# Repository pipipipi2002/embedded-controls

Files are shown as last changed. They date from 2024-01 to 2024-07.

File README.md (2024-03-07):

# The Hardware
- [Interactive BOM](https://pipipipi2002.github.io/embedded-controls/hardware/controls-carier-board/output/interactive_bom.html)

## MCU
This sensor module will require the STM32F446VETx Module from [stm32f446vetx-dev-module](https://github.com/pipipipi2002/stm32f446vetx-dev-module)

## Sensor
No | Sensor | Description | Connection
---| --- |--- | ---
1  | ICM-40609-D | 6-axis IMU | SPI1
2  | ICM-42688-P | 6-axis IMU | SPI3
3  | BNO085      | 9-axis IMU | SPI2
4  | BMP390      | Barometer  | SPI4

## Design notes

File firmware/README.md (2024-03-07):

# Firmware
Capabilities
- Library support for 
    - 9-Axis IMU BNO08X
    - 6-Axis IMU ICM42688P
    - 6-Axis IMU ICM40609D
- Outputs data through UART (connected to the USB-C)

# Usage
```bash
$ make all      # to build 
$ make all -j8  # build with 8 worker cores
$ make stflash  # to flash
$ make clean    # to delete build outputs
```

## Dependencies
- Make and CMake
- GNU ARM toolchain
- Vscode
- OpenOCD [(install guide)](https://forum.pedalpcb.com/threads/setting-up-vscode-openocd-xpack-st-link-for-debugging-on-macos-big-sur.4861/)
- SVD file (already provided but you can get it from [here](https://github.com/cmsis-svd/cmsis-svd-data))

# VS-code 
## Setting Up
Download the necessaries extensions
- Cortex-Debug
- C/C++

Navigate to `.vscode` and edit the following files
- `c_cpp_properties.json`
    - Edit `macFrameworkPath` to your own environment
- `launch.json`
    - `configFiles`: based on the OpenOCD xpack install path
- `settings.json`
    - `cortex-debug.armToolchainPath`: to your GCC ARM toolchain path
    - `C_Cpp.default.compilerPath`: to your GCC ARM toolchain path

## Tasks
Under build group, there are 3 preconfigured tasks, same as in the Usage Section above.
Press `Ctrl+Shift+B` to bring up the vscode build panel and choose the desired action.

## Debug 
Under Debug, there are 2 preconfigured launches, as defined in `vscode/launch.json`. 
- Debug (with build)
- Attach

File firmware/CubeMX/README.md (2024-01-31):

# Details
This folder contains generated files from CubeMX (not the one inside STM32CubeIDE). The Makefile can be ignored as the overall project uses CMake which does not depend on the generated Makefile.

The startup file and linkerscript is depended by the top level CMakeLists.txt

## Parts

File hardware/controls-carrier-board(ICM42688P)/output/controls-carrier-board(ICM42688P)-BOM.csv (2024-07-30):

Comment | Designator | Footprint | LCSC
10n | C1,C2,C9,C10 | Capacitor_SMD:C_0402_1005Metric | C361206
1u | C17 | Capacitor_SMD:C_0603_1608Metric | C5673
470p | C18 | Capacitor_SMD:C_0603_1608Metric | C519409
2u2 | C19 | Capacitor_Tantalum_SMD:CP_EIA-3216-18_Kemet-A_Pad1.58x1.35mm_HandSolder | C600494
2u2 | C3,C4,C11,C12 | Capacitor_SMD:C_0402_1005Metric | C368595
0u1 | C5,C6,C7,C8,C13,C14,C15,C16 | Capacitor_SMD:C_0402_1005Metric | C432917
BAT760 | D1 | Diode_SMD:D_SOD-323 | C124187
LED | D2,D3 | LED_SMD:LED_0603_1608Metric | C131281
DF40HC_4.0_-60DS-0.4V_51_ | J1,J2 | whose_lib:DF40HC4060DS04V51 | C3647944
22 | R1,R2,R3,R4,R5,R6,R7,R8,R9,R10,R13,R14,R15,R16,R17,R18,R19,R20,R21,R22,R23,R25,R26,R27,R28,R29 | Resistor_SMD:R_0402_1005Metric | C413049
330 | R11,R12 | Resistor_SMD:R_0603_1608Metric | C441887
ICM-42688-P | U1,U2,U4,U5 | whose_lib:ICM_LGA-14_3x2.5mm_P0.5mm | C1850418
BMM150 | U3 | Package_CSP:WLCSP-12_1.56x1.56mm_P0.4mm | C171681
BMP390 | U6 | whose_lib:Bosch_LGA-10_2x2mm_P0.50mm | C9900016584
MIC5219-3.3YM5 | U7 | Package_TO_SOT_SMD:SOT-23-5 | C29613

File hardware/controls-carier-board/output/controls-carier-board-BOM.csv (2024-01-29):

Comment | Designator | Footprint | LCSC
10n | C1,C7 | Capacitor_SMD:C_0603_1608Metric | C307346
1u | C14 | Capacitor_SMD:C_0603_1608Metric | C5673
470p | C15 | Capacitor_SMD:C_0603_1608Metric | C519409
2u2 | C16 | Capacitor_Tantalum_SMD:CP_EIA-3216-18_Kemet-A_Pad1.58x1.35mm_HandSolder | C600494
2u2 | C2,C8 | Capacitor_SMD:C_0603_1608Metric | C100082
0u1 | C3,C4,C5,C6,C9,C10,C11 | Capacitor_SMD:C_0603_1608Metric | C1591
BAT760 | D1 | Diode_SMD:D_SOD-323 | C124187
LED | D2,D3 | LED_SMD:LED_0603_1608Metric | C131281
DF40HC_4.0_-60DS-0.4V_51_ | J1,J2 | whose_lib:DF40HC4060DS04V51 | C3647944
22 | R1,R2,R3,R4,R5,R6,R9,R10,R11,R12,R13,R14,R15,R16,R17,R18,R19,R20,R21,R22,R23,R24,R31,R32 | Resistor_SMD:R_0603_1608Metric | C491194
330 | R33,R34 | Resistor_SMD:R_0603_1608Metric | C441887
10k | R7,R8 | Resistor_SMD:R_0603_1608Metric | C98220
SW_DIP_x02 | SW1 | whose_lib:218-2LPSTRF | C314498
ICM-40609-D | U1 | whose_lib:ICM_LGA-24_3x3mm-P0.4mm | C5360621
BNO085X | U2 | Package_LGA:LGA-28_5.2x3.8mm_P0.5mm | C5189642
ICM-42688-P | U3 | whose_lib:ICM_LGA-14_3x2.5mm_P0.5mm | C1850418
BMP390 | U4 | whose_lib:Bosch_LGA-10_2x2mm_P0.50mm | C9900016584
MIC5219-3.3YM5 | U6 | Package_TO_SOT_SMD:SOT-23-5 | C29613

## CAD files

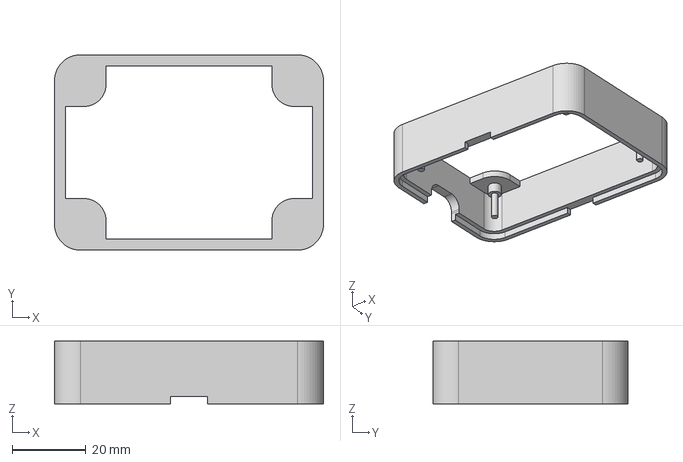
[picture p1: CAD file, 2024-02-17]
hardware/Casing-Sensor_3D-print/module-case-sensor_BODY.step
73.0 x 53.0 x 17.0 mm

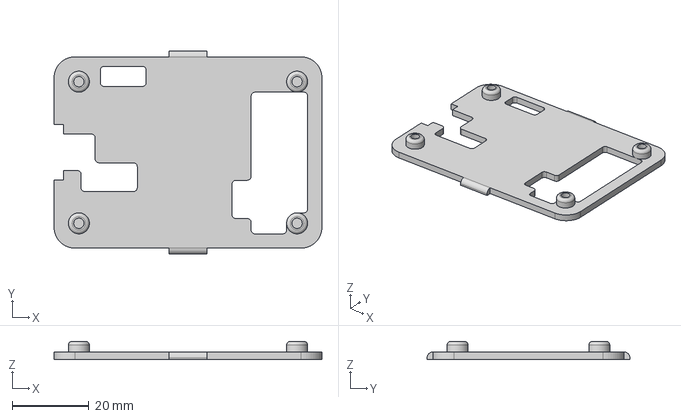
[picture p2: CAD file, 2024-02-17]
hardware/Casing-Sensor_3D-print/module-case-sensor_TOP.step
70.0 x 53.0 x 4.80 mm

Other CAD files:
hardware/Casing-Sensor_3D-print/module-case-sensor.f3z

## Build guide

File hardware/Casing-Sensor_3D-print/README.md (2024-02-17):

# Simple 3D-Printable casing
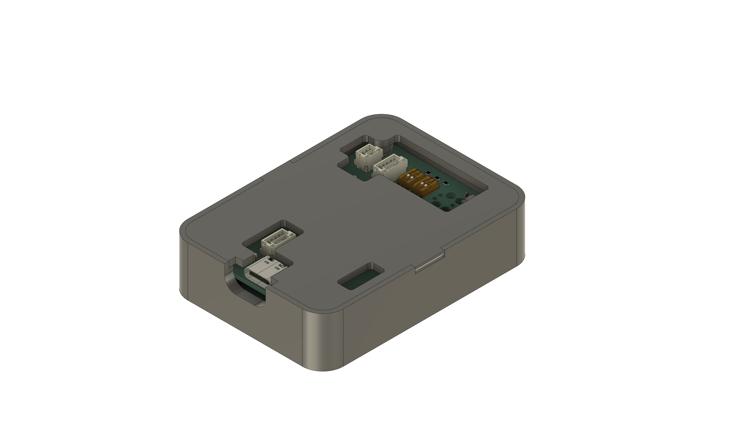
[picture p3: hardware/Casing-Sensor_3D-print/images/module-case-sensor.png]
Overview

Exploding view
## Body
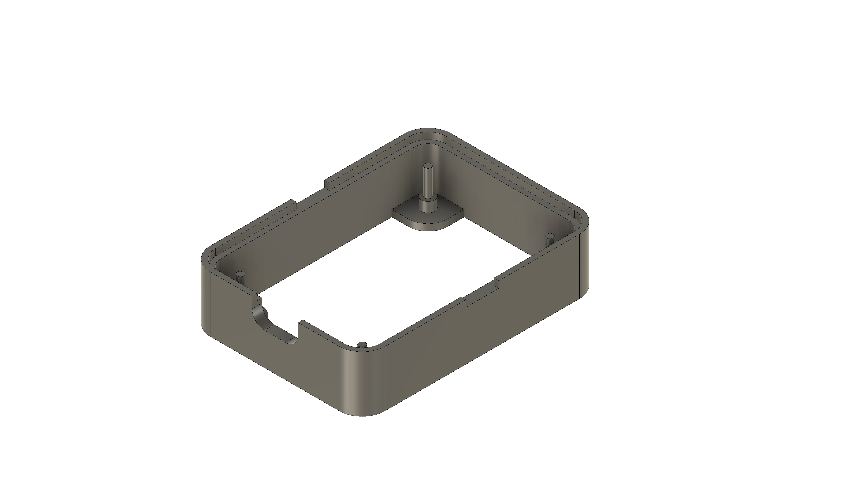
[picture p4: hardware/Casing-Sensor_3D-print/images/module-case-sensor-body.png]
Body

## Top
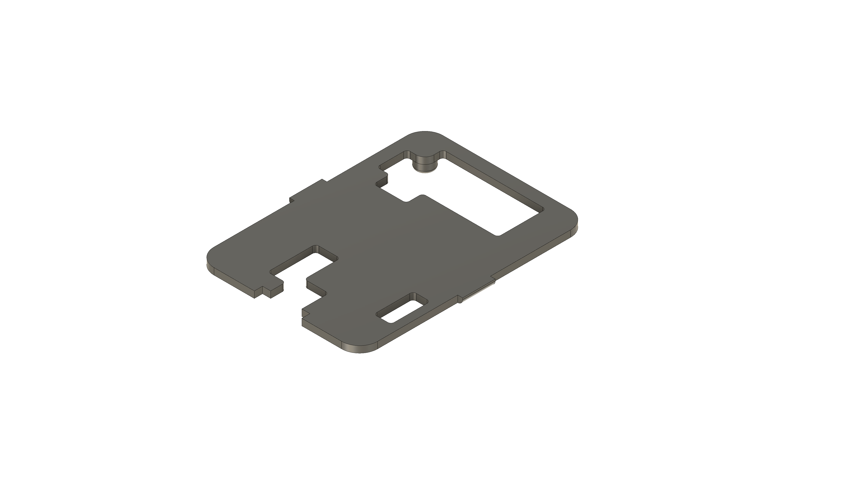
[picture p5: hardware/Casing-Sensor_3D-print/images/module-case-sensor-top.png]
Top

## Body & PCB
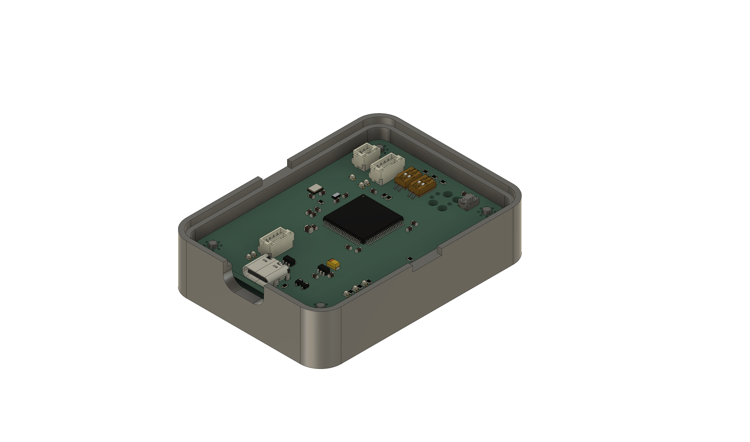
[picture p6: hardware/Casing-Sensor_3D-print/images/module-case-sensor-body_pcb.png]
Body&PCB


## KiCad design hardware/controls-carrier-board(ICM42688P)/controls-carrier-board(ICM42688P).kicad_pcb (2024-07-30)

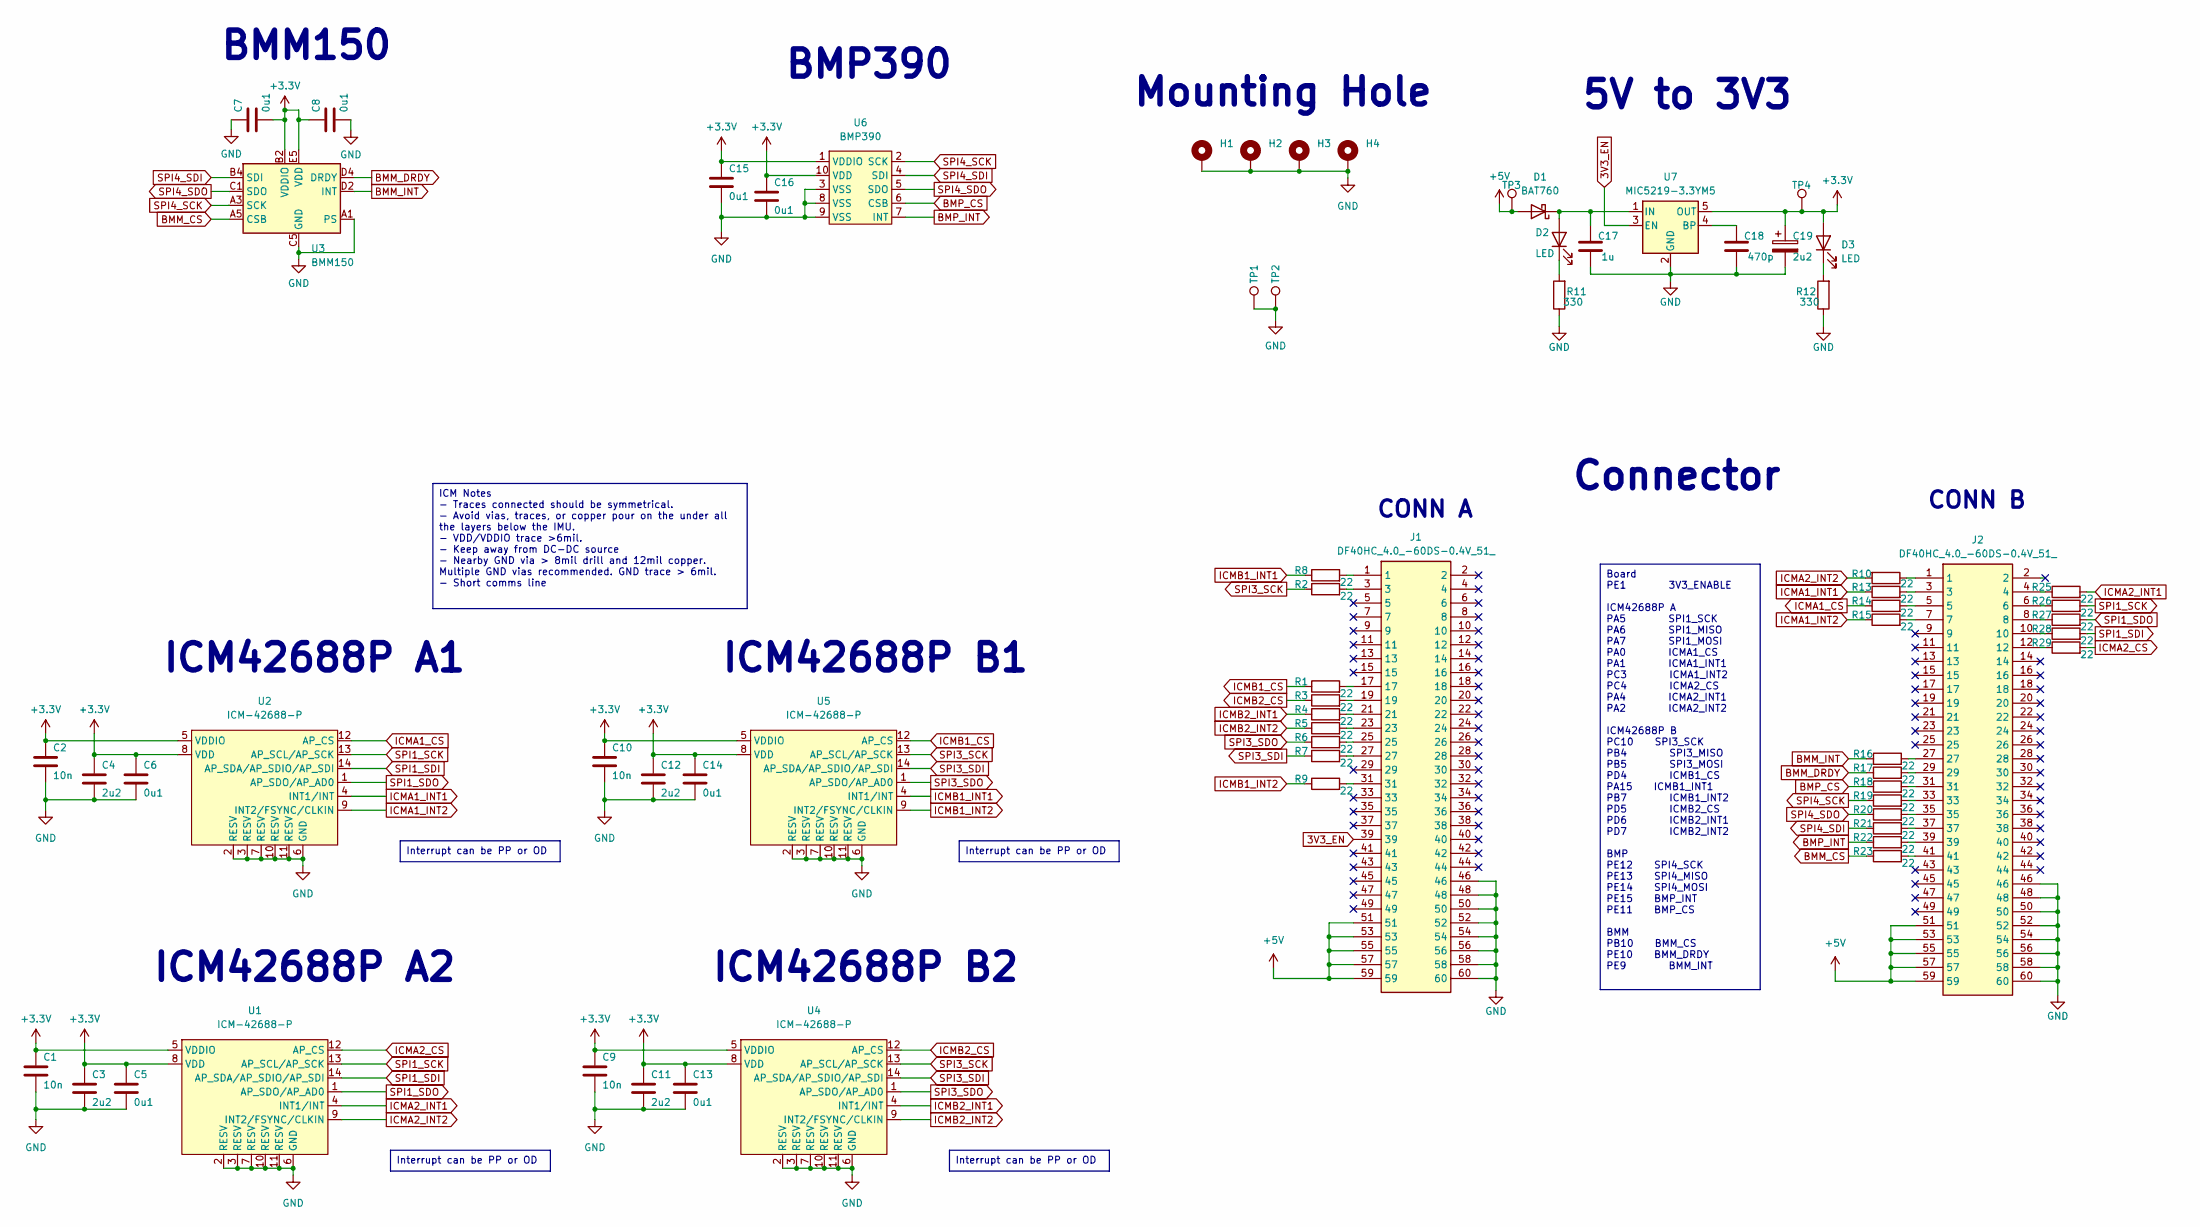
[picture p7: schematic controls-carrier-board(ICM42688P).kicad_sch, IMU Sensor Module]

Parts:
C1, C2, C9, C10: 10n; C_0402_1005Metric; JLCPCB C361206
C3, C4, C11, C12: 2u2; C_0402_1005Metric; JLCPCB C368595
C5, C6, C7, C8, C13, C14, C15, C16: 0u1; C_0402_1005Metric; JLCPCB C432917
C17: 1u; C_0603_1608Metric; JLCPCB C5673
C18: 470p; C_0603_1608Metric; JLCPCB C519409
C19: 2u2; CP_EIA-3216-18_Kemet-A_Pad1.58x1.35mm_HandSolder; JLCPCB C600494
D1: BAT760; D_SOD-323; JLCPCB C124187
D2, D3: LED; LED_0603_1608Metric; JLCPCB C131281
H1, H2, H3, H4: MountingHole_Pad; MountingHole_2.7mm_M2.5_Pad_Via
J1, J2: DF40HC_4.0_-60DS-0.4V_51_; DF40HC4060DS04V51; Mouser Part Number 798-DF4HC4060DS04V51
R1, R2, R3, R4, R5, R6, R7, R8, R9, R10, R13, R14, R15, R16, R17, R18, R19, R20, R21, R22, R23, R25, R26, R27, R28, R29: 22; R_0402_1005Metric; JLCPCB C413049
R11, R12: 330; R_0603_1608Metric; JLCPCB C441887
TP1, TP2, TP3, TP4: TestPoint; TestPoint_Keystone_5000-5004_Miniature
U1, U2, U4, U5: ICM-42688-P; ICM_LGA-14_3x2.5mm_P0.5mm; JLCPCB C1850418
U3: BMM150; WLCSP-12_1.56x1.56mm_P0.4mm; JLCPCB C171681
U6: BMP390; Bosch_LGA-10_2x2mm_P0.50mm; JLCPCB C9900016584
U7: MIC5219-3.3YM5; SOT-23-5; JLCPCB C29613

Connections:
3V3_EN: J1.39, U7.3 (EN)
+3.3V: C1.1, C2.1, C3.1, C4.1, C5.1, C6.1, C7.2, C8.1, C9.1, C10.1, C11.1, C12.1, C13.1, C14.1, C15.1, C16.1, C19.1, D3.2 (A), TP4.1, U1.5 (VDDIO), U1.8 (VDD), U2.5 (VDDIO), U2.8 (VDD), U3.B2 (VDDIO), U3.E5 (VDD), U4.5 (VDDIO), U4.8 (VDD), U5.5 (VDDIO), U5.8 (VDD), U6.1 (VDDIO), U6.10 (VDD), U7.5 (OUT)
+5V: D1.2 (A), J1.51, J1.53, J1.55, J1.57, J1.59, J2.51, J2.53, J2.55, J2.57, J2.59, TP3.1
BMM_CS: R23.1, U3.A5 (CSB)
BMM_DRDY: R17.1, U3.D4 (DRDY)
BMM_INT: R16.1, U3.D2 (INT)
BMP_CS: R18.1, U6.6 (CSB)
BMP_INT: R22.1, U6.7 (INT)
GND: C1.2, C2.2, C3.2, C4.2, C5.2, C6.2, C7.1, C8.2, C9.2, C10.2, C11.2, C12.2, C13.2, C14.2, C15.2, C16.2, C17.2, C18.2, C19.2, H1.1, H2.1, H3.1, H4.1, J1.46, J1.48, J1.50, J1.52, J1.54, J1.56, J1.58, J1.60, J2.46, J2.48, J2.50, J2.52, J2.54, J2.56, J2.58, J2.60, R11.1, R12.1, TP1.1, TP2.1, U1.2 (RESV), U1.3 (RESV), U1.6 (GND), U1.7 (RESV), U1.10 (RESV), U1.11 (RESV), U2.2 (RESV), U2.3 (RESV), U2.6 (GND), U2.7 (RESV), U2.10 (RESV), U2.11 (RESV), U3.A1 (PS), U3.C5 (GND), U3.E1 (GND), U3.E3 (GND), U4.2 (RESV), U4.3 (RESV), U4.6 (GND), U4.7 (RESV), U4.10 (RESV), U4.11 (RESV), U5.2 (RESV), U5.3 (RESV), U5.6 (GND), U5.7 (RESV), U5.10 (RESV), U5.11 (RESV), U6.3 (VSS), U6.8 (VSS), U6.9 (VSS), U7.2 (GND)
ICMA1_CS: R14.1, U2.12 (AP_CS)
ICMA1_INT1: R13.1, U2.4 (INT1/INT)
ICMA1_INT2: R15.1, U2.9 (INT2/FSYNC/CLKIN)
ICMA2_CS: R29.2, U1.12 (AP_CS)
ICMA2_INT1: R25.2, U1.4 (INT1/INT)
ICMA2_INT2: R10.2, U1.9 (INT2/FSYNC/CLKIN)
ICMB1_CS: R1.1, U5.12 (AP_CS)
ICMB1_INT1: R8.1, U5.4 (INT1/INT)
ICMB1_INT2: R9.1, U5.9 (INT2/FSYNC/CLKIN)
ICMB2_CS: R3.1, U4.12 (AP_CS)
ICMB2_INT1: R4.1, U4.4 (INT1/INT)
ICMB2_INT2: R5.1, U4.9 (INT2/FSYNC/CLKIN)
unnamed: C17.1, D1.1 (K), D2.2 (A), U7.1 (IN)
unnamed: D2.1 (K), R11.2
unnamed: D3.1 (K), R12.2
unnamed: J1.1, R8.2
unnamed: J1.3, R2.2
unnamed: J1.17, R1.2
unnamed: J1.19, R3.2
unnamed: J1.21, R4.2
unnamed: J1.23, R5.2
unnamed: J1.25, R6.2
unnamed: J1.27, R7.2
unnamed: J1.31, R9.2
unnamed: J2.1, R10.1
unnamed: J2.3, R13.2
unnamed: J2.4, R25.1
unnamed: J2.5, R14.2
unnamed: J2.6, R26.1
unnamed: J2.7, R15.2
unnamed: J2.8, R27.1
unnamed: J2.10, R28.1
unnamed: J2.12, R29.1
unnamed: J2.27, R16.2
unnamed: J2.29, R17.2
unnamed: J2.31, R18.2
unnamed: J2.33, R19.2
unnamed: J2.35, R20.2
unnamed: J2.37, R21.2
unnamed: J2.39, R22.2
unnamed: J2.41, R23.2
unnamed: C18.1, U7.4 (BP)
SPI1_SCK: R26.2, U1.13 (AP_SCL/AP_SCK), U2.13 (AP_SCL/AP_SCK)
SPI1_SDI: R28.2, U1.14 (AP_SDA/AP_SDIO/AP_SDI), U2.14 (AP_SDA/AP_SDIO/AP_SDI)
SPI1_SDO: R27.2, U1.1 (AP_SDO/AP_AD0), U2.1 (AP_SDO/AP_AD0)
SPI3_SCK: R2.1, U4.13 (AP_SCL/AP_SCK), U5.13 (AP_SCL/AP_SCK)
SPI3_SDI: R7.1, U4.14 (AP_SDA/AP_SDIO/AP_SDI), U5.14 (AP_SDA/AP_SDIO/AP_SDI)
SPI3_SDO: R6.1, U4.1 (AP_SDO/AP_AD0), U5.1 (AP_SDO/AP_AD0)
SPI4_SCK: R19.1, U3.A3 (SCK), U6.2 (SCK)
SPI4_SDI: R21.1, U3.B4 (SDI), U6.4 (SDI)
SPI4_SDO: R20.1, U3.C1 (SDO), U6.5 (SDO)

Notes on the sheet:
Board PE1 3V3_ENABLE ICM42688P A PA5 SPI1_SCK PA6 SPI1_MISO PA7 SPI1_MOSI PA0 ICMA1_CS PA1 ICMA1_INT1 PC3 ICMA1_INT2 PC4 ICMA2_CS PA4 ICMA2_INT1 PA2 ICMA2_INT2 ICM42688P B PC10 SPI3_SCK PB4 SPI3_MISO PB5 SPI3_MOSI PD4 ICMB1_CS PA15 ICMB1_INT1 PB7 ICMB1_INT2 PD5 ICMB2_CS PD6 ICMB2_INT1 PD7 ICMB2_INT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
ICM Notes - Traces connected should be symmetrical. - Avoid vias, traces, or copper pour on the under all the layers below the IMU. - VDD/VDDIO trace >6mil. - Keep away from DC-DC source - Nearby GND via > 8mil drill and 12mil copper. Multiple GND vias recommended. GND trace > 6mil. - Short comms l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
Interrupt can be PP or OD
Connector
5V to 3V3
BMM150
ICM42688P B1
Mounting Hole
ICM42688P A2
ICM42688P B2
BMP390
CONN A
ICM42688P A1
CONN B

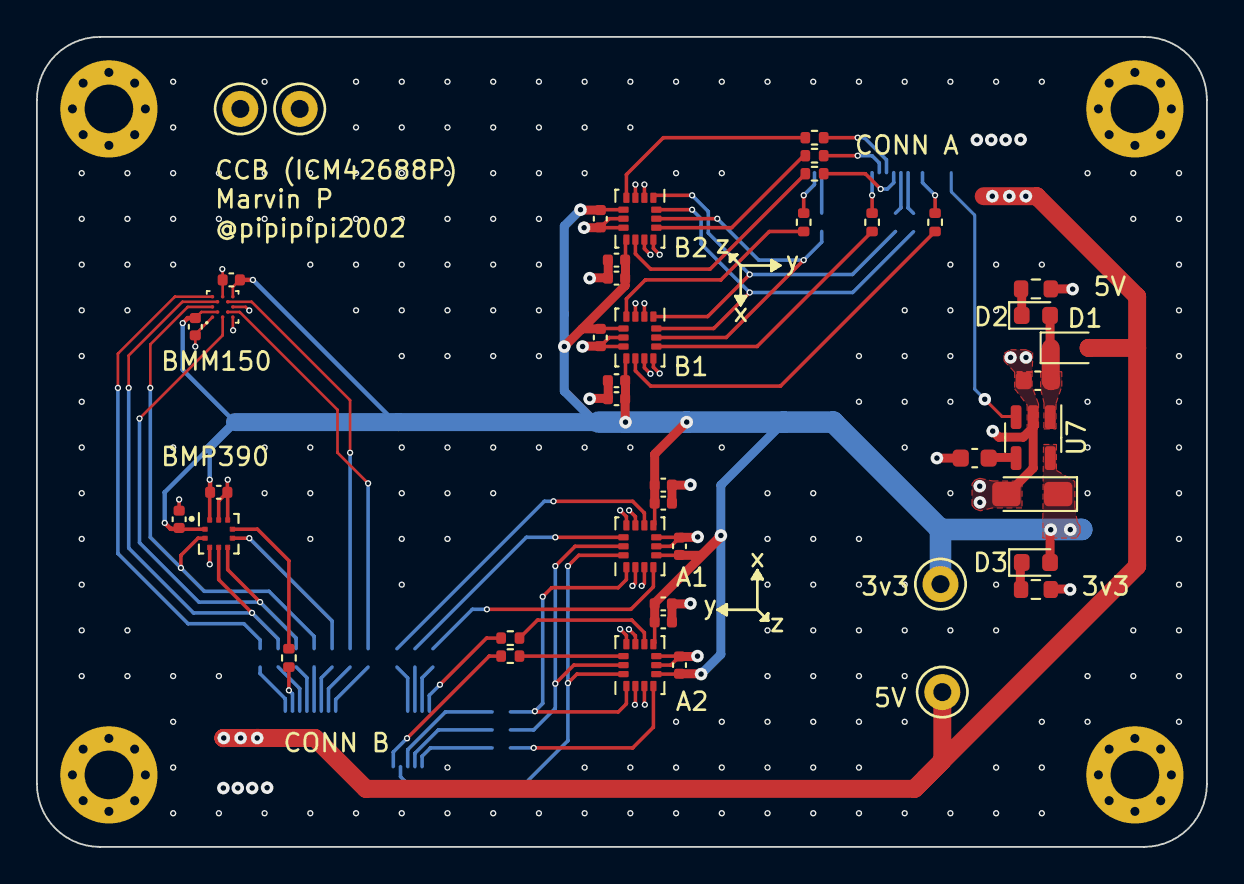
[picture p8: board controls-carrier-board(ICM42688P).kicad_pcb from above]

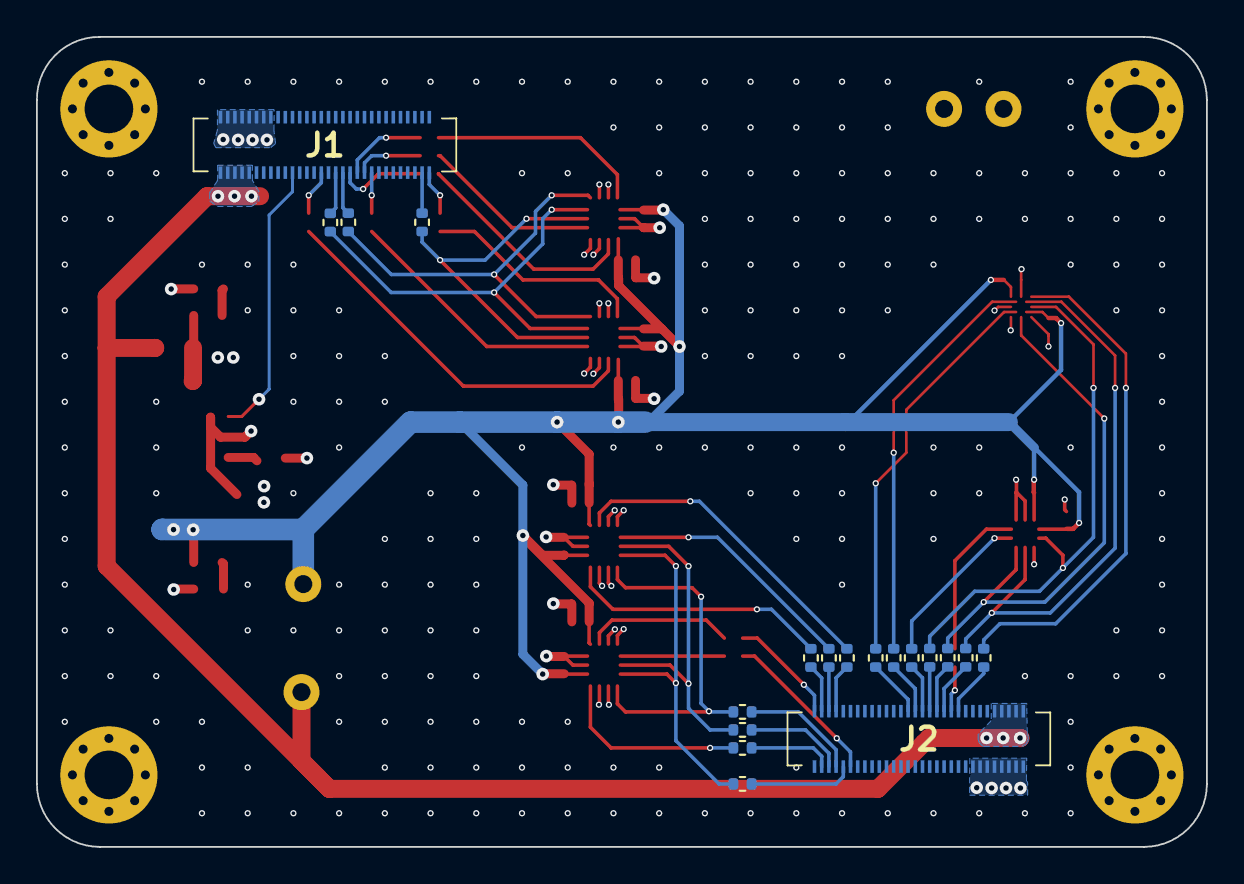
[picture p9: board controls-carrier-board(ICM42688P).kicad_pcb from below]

Board: 4 copper layers, 65.0 x 45.0 mm, 67 parts (19 on the bottom side), 60 nets.

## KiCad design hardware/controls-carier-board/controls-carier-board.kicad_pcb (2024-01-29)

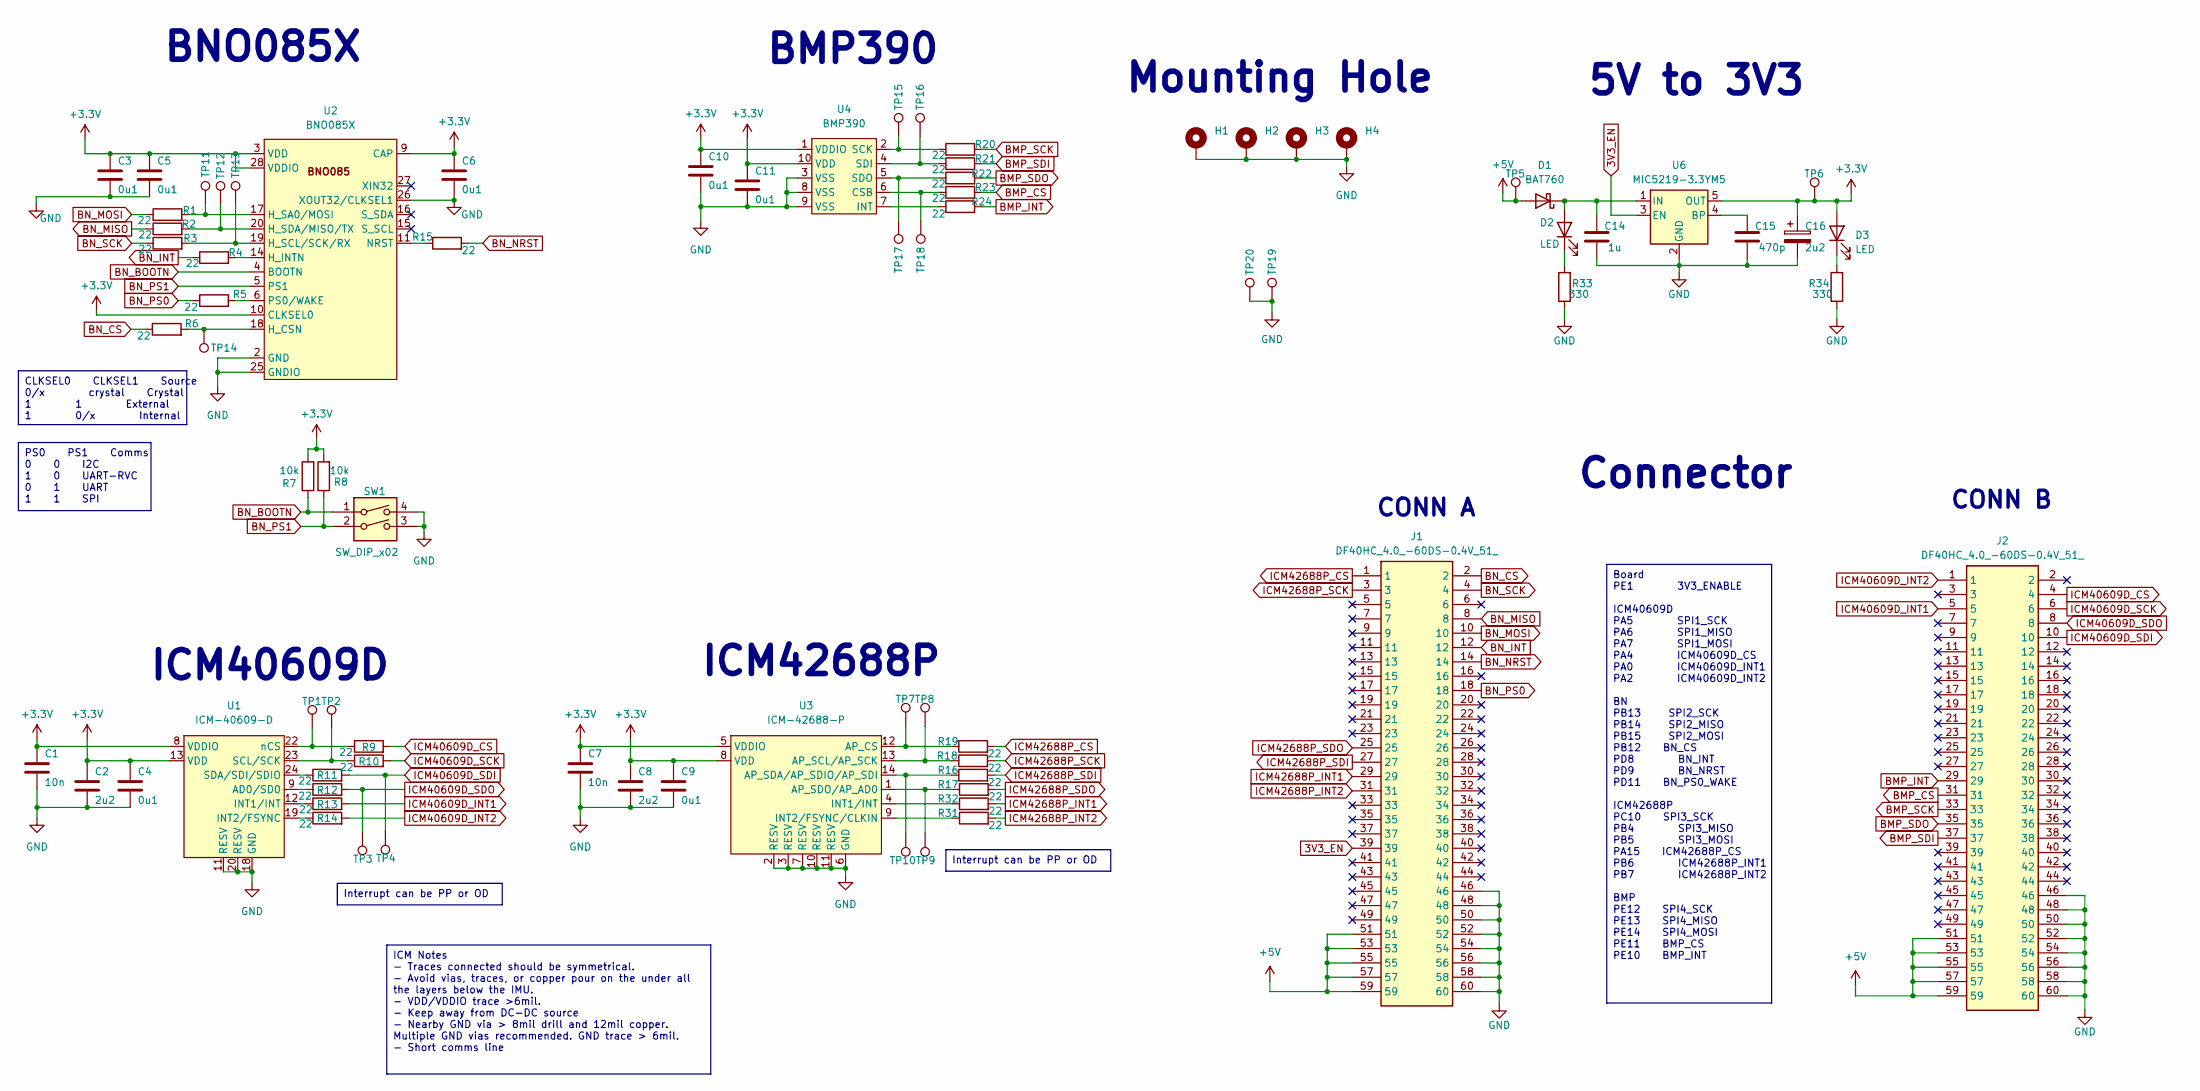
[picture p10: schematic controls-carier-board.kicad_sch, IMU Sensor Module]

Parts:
C1, C7: 10n; C_0603_1608Metric; JLCPCB C307346
C2, C8: 2u2; C_0603_1608Metric; JLCPCB C100082
C3, C4, C5, C6, C9, C10, C11: 0u1; C_0603_1608Metric; JLCPCB C1591
C14: 1u; C_0603_1608Metric; JLCPCB C5673
C15: 470p; C_0603_1608Metric; JLCPCB C519409
C16: 2u2; CP_EIA-3216-18_Kemet-A_Pad1.58x1.35mm_HandSolder; JLCPCB C600494
D1: BAT760; D_SOD-323; JLCPCB C124187
D2, D3: LED; LED_0603_1608Metric; JLCPCB C131281
H1, H2, H3, H4: MountingHole_Pad; MountingHole_2.7mm_M2.5_Pad_Via
J1, J2: DF40HC_4.0_-60DS-0.4V_51_; DF40HC4060DS04V51; Mouser Part Number 798-DF4HC4060DS04V51
R1, R2, R3, R4, R5, R6, R9, R10, R11, R12, R13, R14, R15, R16, R17, R18, R19, R20, R21, R22, R23, R24, R31, R32: 22; R_0603_1608Metric; JLCPCB C491194
R7, R8: 10k; R_0603_1608Metric; JLCPCB C98220
R33, R34: 330; R_0603_1608Metric; JLCPCB C441887
SW1: SW_DIP_x02; 218-2LPSTRF; JLCPCB C314498
TP1, TP2, TP3, TP4, TP5, TP6, TP7, TP8, TP9, TP10, TP11, TP12, TP13, TP14, TP15, TP16, TP17, TP18, TP19, TP20: TestPoint; TestPoint_Keystone_5000-5004_Miniature
U1: ICM-40609-D; ICM_LGA-24_3x3mm-P0.4mm; JLCPCB C5360621
U2: BNO085X; LGA-28_5.2x3.8mm_P0.5mm; JLCPCB C5189642
U3: ICM-42688-P; ICM_LGA-14_3x2.5mm_P0.5mm; JLCPCB C1850418
U4: BMP390; Bosch_LGA-10_2x2mm_P0.50mm; JLCPCB C9900016584
U6: MIC5219-3.3YM5; SOT-23-5; JLCPCB C29613

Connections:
3V3_EN: J1.39, U6.3 (EN)
+3.3V: C1.1, C2.1, C3.1, C4.1, C5.1, C6.1, C7.1, C8.1, C9.1, C10.1, C11.1, C16.1, D3.2 (A), R7.2, R8.2, TP6.1, U1.8 (VDDIO), U1.13 (VDD), U2.3 (VDD), U2.9 (CAP), U2.10 (CLKSEL0), U2.28 (VDDIO), U3.5 (VDDIO), U3.8 (VDD), U4.1 (VDDIO), U4.10 (VDD), U6.5 (OUT)
+5V: D1.2 (A), J1.51, J1.53, J1.55, J1.57, J1.59, J2.51, J2.53, J2.55, J2.57, J2.59, TP5.1
BMP_CS: J2.31, R23.2
BMP_INT: J2.29, R24.2
BMP_SCK: J2.33, R20.2
BMP_SDI: J2.37, R21.2
BMP_SDO: J2.35, R22.2
BN_BOOTN: R7.1, SW1.1, U2.4 (BOOTN)
BN_CS: J1.2, R6.1
BN_INT: J1.12, R4.1
BN_MISO: J1.8, R2.1
BN_MOSI: J1.10, R1.1
BN_NRST: J1.14, R15.2
BN_PS0: J1.18, R5.1
BN_PS1: R8.1, SW1.2, U2.5 (PS1)
BN_SCK: J1.4, R3.1
GND: C1.2, C2.2, C3.2, C4.2, C5.2, C6.2, C7.2, C8.2, C9.2, C10.2, C11.2, C14.2, C15.2, C16.2, H1.1, H2.1, H3.1, H4.1, J1.46, J1.48, J1.50, J1.52, J1.54, J1.56, J1.58, J1.60, J2.46, J2.48, J2.50, J2.52, J2.54, J2.56, J2.58, J2.60, R33.1, R34.1, SW1.3, SW1.4, TP19.1, TP20.1, U1.11 (RESV), U1.18 (GND), U1.20 (RESV), U2.2 (GND), U2.25 (GNDIO), U2.26 (XOUT32/CLKSEL1), U3.2 (RESV), U3.3 (RESV), U3.6 (GND), U3.7 (RESV), U3.10 (RESV), U3.11 (RESV), U4.3 (VSS), U4.8 (VSS), U4.9 (VSS), U6.2 (GND)
ICM40609D_CS: J2.4, R9.2
ICM40609D_INT1: J2.5, R13.2
ICM40609D_INT2: J2.1, R14.2
ICM40609D_SCK: J2.6, R10.2
ICM40609D_SDI: J2.10, R11.2, TP4.1
ICM40609D_SDO: J2.8, R12.2, TP3.1
ICM42688P_CS: J1.1, R19.2
ICM42688P_INT1: J1.29, R32.2
ICM42688P_INT2: J1.31, R31.2
ICM42688P_SCK: J1.3, R18.2
ICM42688P_SDI: J1.27, R16.2
ICM42688P_SDO: J1.25, R17.2
unnamed: C14.1, D1.1 (K), D2.2 (A), U6.1 (IN)
unnamed: D2.1 (K), R33.2
unnamed: D3.1 (K), R34.2
unnamed: R12.1, U1.9 (AD0/SD0)
unnamed: R13.1, U1.12 (INT1/INT)
unnamed: R14.1, U1.19 (INT2/FSYNC)
unnamed: R10.1, TP2.1, U1.23 (SCL/SCK)
unnamed: R11.1, U1.24 (SDA/SDI/SDIO)
unnamed: R9.1, TP1.1, U1.22 (nCS)
unnamed: R6.2, TP14.1, U2.18 (H_CSN)
unnamed: R4.2, U2.14 (H_INTN)
unnamed: R1.2, TP11.1, U2.17 (H_SA0/MOSI)
unnamed: R3.2, TP13.1, U2.19 (H_SCL/SCK/RX)
unnamed: R2.2, TP12.1, U2.20 (H_SDA/MISO/TX)
unnamed: R15.1, U2.11 (NRST)
unnamed: R5.2, U2.6 (PS0/WAKE)
unnamed: R19.1, TP7.1, U3.12 (AP_CS)
unnamed: R18.1, TP8.1, U3.13 (AP_SCL/AP_SCK)
unnamed: R16.1, TP10.1, U3.14 (AP_SDA/AP_SDIO/AP_SDI)
unnamed: R17.1, TP9.1, U3.1 (AP_SDO/AP_AD0)
unnamed: R32.1, U3.4 (INT1/INT)
unnamed: R31.1, U3.9 (INT2/FSYNC/CLKIN)
unnamed: R23.1, TP18.1, U4.6 (CSB)
unnamed: R24.1, U4.7 (INT)
unnamed: R20.1, TP15.1, U4.2 (SCK)
unnamed: R21.1, TP16.1, U4.4 (SDI)
unnamed: R22.1, TP17.1, U4.5 (SDO)
unnamed: C15.1, U6.4 (BP)

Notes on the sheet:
Board PE1 3V3_ENABLE ICM40609D PA5 SPI1_SCK PA6 SPI1_MISO PA7 SPI1_MOSI PA4 ICM40609D_CS PA0 ICM40609D_INT1 PA2 ICM40609D_INT2 BN PB13 SPI2_SCK PB14 SPI2_MISO PB15 SPI2_MOSI PB12 BN_CS PD8 BN_INT PD9 BN_NRST PD11 BN_PS0_WAKE ICM42688P PC10 SPI3_SCK PB4 SPI3_MISO PB5 SPI3_MOSI PA15 ICM42688P_CS PB6 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
CLKSEL0 CLKSEL1 Source 0/x crystal Crystal 1 1 External 1 0/x Internal
ICM Notes - Traces connected should be symmetrical. - Avoid vias, traces, or copper pour on the under all the layers below the IMU. - VDD/VDDIO trace >6mil. - Keep away from DC-DC source - Nearby GND via > 8mil drill and 12mil copper. Multiple GND vias recommended. GND trace > 6mil. - Short comms l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
Interrupt can be PP or OD
PS0 PS1 Comms 0 0 I2C 1 0 UART-RVC 0 1 UART 1 1 SPI
Connector
5V to 3V3
ICM42688P
Mounting Hole
BMP390
CONN A
BNO085X
CONN B
ICM40609D

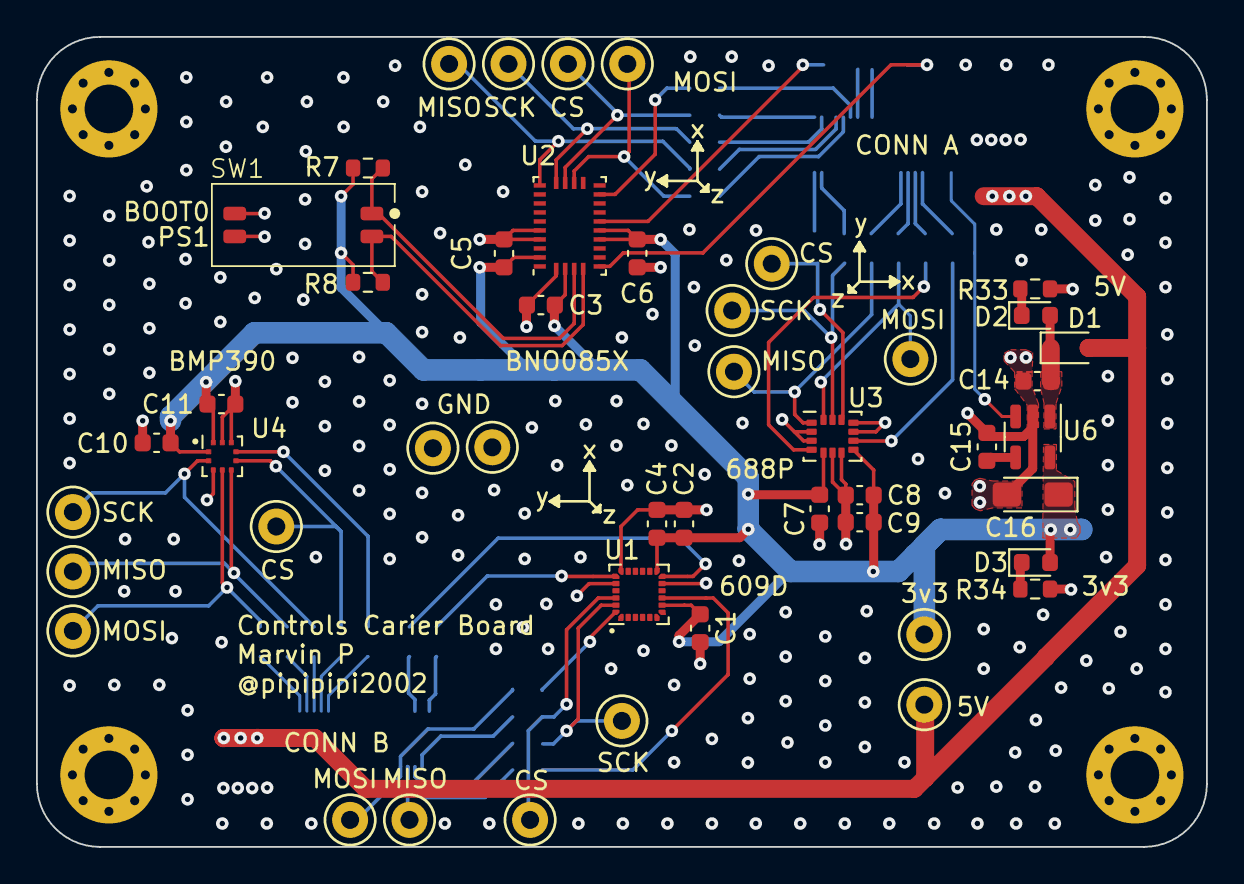
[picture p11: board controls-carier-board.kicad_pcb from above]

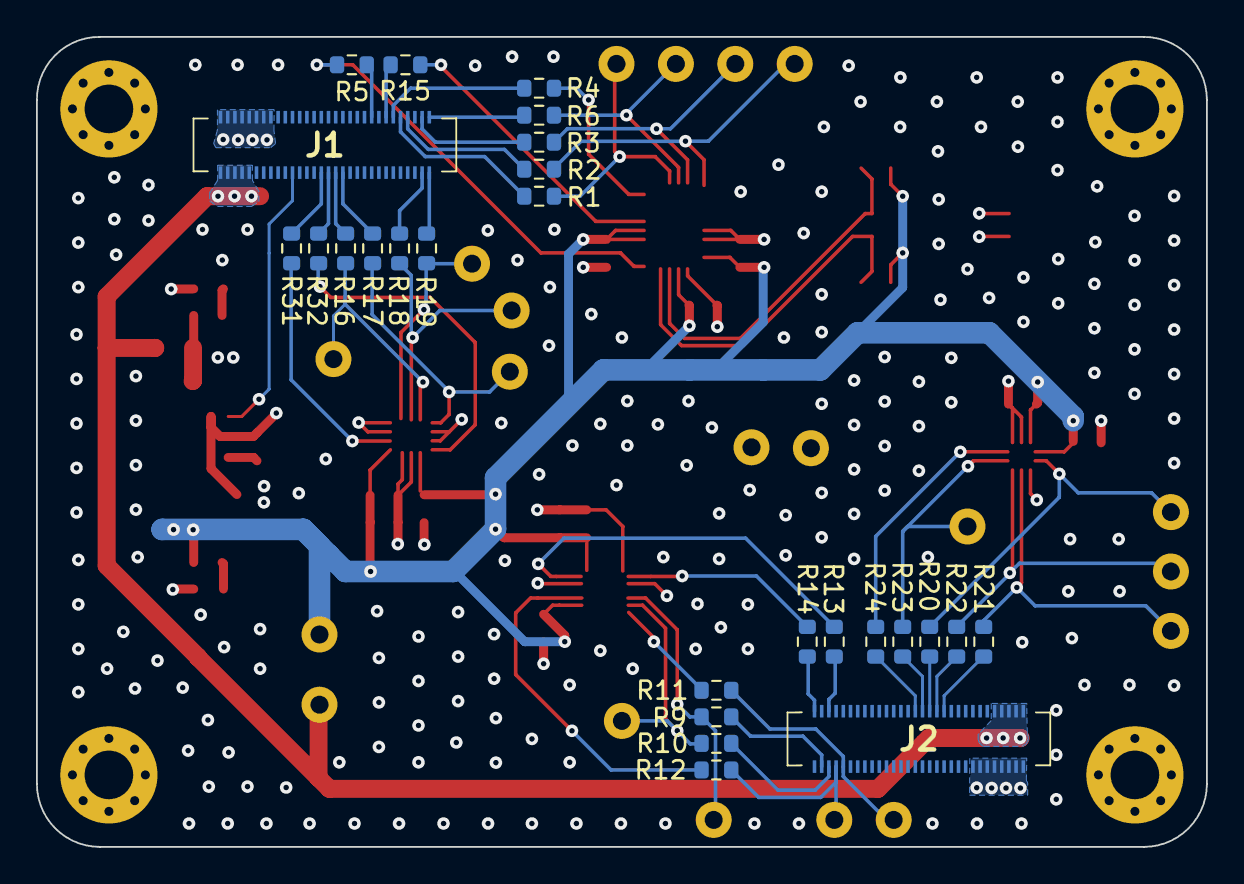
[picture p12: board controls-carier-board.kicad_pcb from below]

Board: 4 copper layers, 65.0 x 45.0 mm, 77 parts (26 on the bottom side), 58 nets.

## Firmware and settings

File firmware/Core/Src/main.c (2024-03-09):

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
/* Includes ------------------------------------------------------------------*/
#include "main.h"

/* USER CODE BEGIN Includes */
#include <printf.h>
#include "icm42688p.h"
#include "icm40609d.h"
#include "icm_driver.h"
/* USER CODE END Includes */


UART_HandleTypeDef huart5;

/* USER CODE BEGIN PV */
float roll, pitch, yaw;
ICM_Config_t icm40609d_cfg = {
  .id = ICM40609D_ID,
  .hal.spi = SPI1,
  .hal.csPort = ICM40609D_CS_GPIO_Port,
  .hal.csPin = ICM40609D_CS_Pin,
  .hal.int1Port = ICM40609D_INT1_GPIO_Port,
  .hal.int1Pin = ICM40609D_INT1_Pin,
  .hal.int2Port = ICM40609D_INT2_GPIO_Port,
  .hal.int2Pin = ICM40609D_INT2_Pin,
};

ICM_Config_t icm42688p_cfg = {
  .id = ICM42688P_ID,
  .hal.spi = SPI3,
  .hal.csPort = ICM42688P_CS_GPIO_Port,
  .hal.csPin = ICM42688P_CS_Pin,
  .hal.int1Port = ICM42688P_INT1_GPIO_Port,
  .hal.int1Pin = ICM42688P_INT1_Pin,
  .hal.int2Port = ICM42688P_INT2_GPIO_Port,
  .hal.int2Pin = ICM42688P_INT2_Pin,
};
/* USER CODE END PV */

void SystemClock_Config(void);
static void MX_GPIO_Init(void);
static void MX_UART5_Init(void);
static void MX_SPI1_Init(void);
static void MX_SPI2_Init(void);
static void MX_SPI3_Init(void);
static void MX_SPI4_Init(void);
/* USER CODE BEGIN PFP */
void sendCsv(ICM_Config_t *icm);
void sendVerbose(ICM_Config_t* icm);
/* USER CODE END PFP */

/**
  * @brief  The application entry point.
  * @retval int
  */
int main(void)
{
  /* MCU Configuration--------------------------------------------------------*/

  /* Reset of all peripherals, Initializes the Flash interface and the Systick. */
  HAL_Init();

  /* Configure the system clock */
  SystemClock_Config();

  /* Initialize all configured peripherals */
  MX_GPIO_Init();
  MX_UART5_Init();
  MX_SPI1_Init();
  MX_SPI2_Init();
  MX_SPI3_Init();
  MX_SPI4_Init();
  /* USER CODE BEGIN 2 */

  printf(PF_SWO, "UART Retarget working.\r\n");  
  
  /* Turns on power to the sensor board */
  LL_GPIO_SetOutputPin(EN_3V3_GPIO_Port, EN_3V3_Pin);

  uint8_t ret = ICM_init(&icm42688p_cfg);
  ret |= ICM_init(&icm40609d_cfg);
  
  if (ret != ICM_OK) {
    printf(PF_SWO, "ICM init failed\r\n");
    Error_Handler();
  }
  else 
  {
    printf(PF_SWO, "ICM init completed\r\n");
  }

  ICM_calibGyro(&icm42688p_cfg);
  ICM_calibGyro(&icm40609d_cfg);
  // printf(PF_DEF, "688 Gyro Bias X Y Z: %0.2f %0.2f %0.2f\r\n", ICM_getGyroBiasX(&icm42688p_cfg), ICM_getGyroBiasY(&icm42688p_cfg), ICM_getGyroBiasZ(&icm42688p_cfg));
  // printf(PF_DEF, "609 Gyro Bias X Y Z: %0.2f %0.2f %0.2f\r\n", ICM_getGyroBiasX(&icm40609d_cfg), ICM_getGyroBiasY(&icm40609d_cfg), ICM_getGyroBiasZ(&icm40609d_cfg));

  /* USER CODE END 2 */

  /* Infinite loop */
  /* USER CODE BEGIN WHILE */
  while (1)
  {
    /* USER CODE END WHILE */

    /* USER CODE BEGIN 3 */
    ICM_updateAllData(&icm42688p_cfg);
    sendCsv(&icm42688p_cfg);
    HAL_Delay(150);
  }
  /* USER CODE END 3 */
}

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
/* USER CODE BEGIN 4 */
void sendCsv(ICM_Config_t *icm) 
{
  float ax, ay, az, gx, gy, gz, temp;
  ax = ICM_getAccX(icm);
  ay = ICM_getAccY(icm);
  az = ICM_getAccZ(icm);
  gx = ICM_getGyroX(icm);
  gy = ICM_getGyroY(icm);
  gz = ICM_getGyroZ(icm);
  temp = ICM_getTemp(icm);

  printf(PF_DEF, "%d,%.04f,%.04f,%.04f,%.04f,%.04f,%.04f\r", (int)temp, ax, ay, az, gx, gy, gz);
}

void sendVerbose(ICM_Config_t* icm)
{
    printf(PF_DEF, "DEV: 0x%H\r\n", icm->id);
    printf(PF_DEF, "\tTemp: %d\r\n", (int)ICM_getTemp(icm));
    printf(PF_DEF, "\taccelX: %.02f ", ICM_getAccX(icm));
    printf(PF_DEF, "\taccelY: %.02f ", ICM_getAccY(icm));
    printf(PF_DEF, "\taccelZ: %.02f\r\n", ICM_getAccZ(icm));
    printf(PF_DEF, "\tGyroX: %.02f ", ICM_getGyroX(icm));
    printf(PF_DEF, "\tGyroY: %.02f ", ICM_getGyroY(icm));
    printf(PF_DEF, "\tGyroZ: %.02f\r\n", ICM_getGyroZ(icm));
}

/**
 * @brief For printf Library submodule.
 * 
 * @param character
 */
void _putchar(char character)
{
  HAL_UART_Transmit(&huart5, (const uint8_t*) &character, 1, 10);
}

/**
 * @brief For printf Library submodule. For SWO purposes
 * 
 * @param character
 */
void _putchar_swo(char character)
{
  ITM_SendChar(character);
}

/* USER CODE END 4 */
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


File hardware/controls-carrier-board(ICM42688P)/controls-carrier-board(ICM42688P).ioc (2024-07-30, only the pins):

Mcu.UserName=STM32F446VETx
PA0-WKUP.GPIO_Label=ICMA1_CS
PA0-WKUP.Signal=GPIO_Input
PA1.GPIO_Label=ICMA1_INT1
PA1.Signal=GPIO_Input
PA13.Signal=SYS_JTMS-SWDIO
PA14.Signal=SYS_JTCK-SWCLK
PA15.GPIO_Label=ICMB1_INT1
PA15.Signal=GPIO_Input
PA2.GPIO_Label=ICMA2_INT2
PA2.Signal=GPIO_Input
PA4.GPIO_Label=ICMA2_INT1
PA4.Signal=GPIO_Output
PA5.Signal=SPI1_SCK
PA6.Signal=SPI1_MISO
PA7.Signal=SPI1_MOSI
PB1.Signal=SDIO_D2
PB10.GPIO_Label=BMM_CS
PB10.Signal=GPIO_Input
PB2.Signal=SDIO_CK
PB3.Signal=SYS_JTDO-SWO
PB4.Signal=SPI3_MISO
PB5.Signal=SPI3_MOSI
PB7.GPIO_Label=ICMB1_INT2
PB7.Signal=GPIO_Input
PB8.Signal=CAN1_RX
PB9.Signal=CAN1_TX
PC10.Signal=SPI3_SCK
PC11.Signal=SDIO_D3
PC14-OSC32_IN.Signal=RCC_OSC32_IN
PC15-OSC32_OUT.Signal=RCC_OSC32_OUT
PC3.GPIO_Label=ICMA1_INT2
PC3.Signal=GPIO_Input
PC4.GPIO_Label=ICMA2_CS
PC4.Signal=GPIO_Output
PC8.Signal=SDIO_D0
PC9.Signal=SDIO_D1
PD10.GPIO_Label=SDIO_nDET
PD10.Signal=GPIO_Input
PD2.Signal=SDIO_CMD
PD4.GPIO_Label=ICMB1_CS
PD4.Signal=GPIO_Output
PD5.GPIO_Label=ICMB2_CS
PD5.Signal=GPIO_Output
PD6.GPIO_Label=ICMB2_INT1
PD6.Signal=GPIO_Input
PD7.GPIO_Label=ICMB2_INT2
PD7.Signal=GPIO_Input
PE1.GPIO_Label=EN_3V3
PE1.Signal=GPIO_Output
PE10.GPIO_Label=BMM_DRDY
PE10.Signal=GPIO_Input
PE11.GPIO_Label=BMP_CS
PE11.Signal=GPIO_Output
PE12.Signal=SPI4_SCK
PE13.Signal=SPI4_MISO
PE14.Signal=SPI4_MOSI
PE15.GPIO_Label=BMP_INT
PE15.Signal=GPIO_Output
PE3.GPIO_Label=GP_LED
PE3.Signal=GPIO_Output
PE7.Signal=UART5_RX
PE8.Signal=UART5_TX
PE9.GPIO_Label=BMM_INT
PE9.Signal=GPIO_Input
PH0-OSC_IN.Signal=RCC_OSC_IN
PH1-OSC_OUT.Signal=RCC_OSC_OUT

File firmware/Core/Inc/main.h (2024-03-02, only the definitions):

#define GP_LED_Pin LL_GPIO_PIN_3
#define GP_LED_GPIO_Port GPIOE
#define ICM40609D_INT1_Pin LL_GPIO_PIN_0
#define ICM40609D_INT1_GPIO_Port GPIOA
#define ICM40609D_INT2_Pin LL_GPIO_PIN_2
#define ICM40609D_INT2_GPIO_Port GPIOA
#define ICM40609D_CS_Pin LL_GPIO_PIN_4
#define ICM40609D_CS_GPIO_Port GPIOA
#define BMP_INT_Pin LL_GPIO_PIN_10
#define BMP_INT_GPIO_Port GPIOE
#define BMP_CS_Pin LL_GPIO_PIN_11
#define BMP_CS_GPIO_Port GPIOE
#define BN_CS_Pin LL_GPIO_PIN_12
#define BN_CS_GPIO_Port GPIOB
#define BN_INT_Pin LL_GPIO_PIN_8
#define BN_INT_GPIO_Port GPIOD
#define BN_NRST_Pin LL_GPIO_PIN_9
#define BN_NRST_GPIO_Port GPIOD
#define SDIO_nDET_Pin LL_GPIO_PIN_10
#define SDIO_nDET_GPIO_Port GPIOD
#define BN_PS0_WAKE_Pin LL_GPIO_PIN_11
#define BN_PS0_WAKE_GPIO_Port GPIOD
#define ICM42688P_CS_Pin LL_GPIO_PIN_15
#define ICM42688P_CS_GPIO_Port GPIOA
#define ICM42688P_INT1_Pin LL_GPIO_PIN_6
#define ICM42688P_INT1_GPIO_Port GPIOB
#define ICM42688P_INT2_Pin LL_GPIO_PIN_7
#define ICM42688P_INT2_GPIO_Port GPIOB
#define EN_3V3_Pin LL_GPIO_PIN_1
#define EN_3V3_GPIO_Port GPIOE
#define ENABLE_3V3_SENSOR_BOARD     LL_GPIO_SetOutputPin(EN_3V3_GPIO_Port, EN_3V3_Pin)
#define DISABLE_3V3_SENSOR_BOARD    LL_GPIO_ResetOutputPin(EN_3V3_GPIO_Port, EN_3V3_Pin)

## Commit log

2024-01-29 fab version
    [controls-carier-board-BOM.csv, controls-carier-board.kicad_pcb, controls-carier-board.kicad_sch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]
2024-01-29 added bom
2024-02-17 added 3d print files
    [module-case-sensor.f3z, module-case-sensor_BODY.step, module-case-sensor_TOP.step]
2024-02-25 fix: update SPI baud rate prescaler and clock phase/polarity for SPI1, SPI2, SPI3, and SPI4
    [controls-carier-board.ioc, main.c]
2024-03-04 Added calibration codes
2024-03-07 Tested on boards
2024-03-07 Switch printf to own fork
2024-03-07 new printf fork implemented and tested
2024-07-30 Added ICM42688P version
    [controls-carrier-board(ICM42688P)-BOM.csv, controls-carrier-board(ICM42688P).kicad_pcb, controls-carrier-board(ICM42688P).kicad_sch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]

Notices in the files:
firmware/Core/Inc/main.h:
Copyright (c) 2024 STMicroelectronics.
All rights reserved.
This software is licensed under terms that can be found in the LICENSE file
